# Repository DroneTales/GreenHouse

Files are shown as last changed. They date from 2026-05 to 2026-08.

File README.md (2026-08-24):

# Контроллер теплицы для Apple Home

Здесь вы найдете прошивку и схему контроллера теплицы, совместимого с Apple Home. Так же, здесь представлены Python скрипты для запуска логгера температуры и WEB-интерфейса контрля температуры, которые вы можете запустить на своем домашнем сервере. По любым вопросам добро пожаловать в мой [телеграм канале](t.me/drone_tales).  

**Используемые компоненты**

- LilyGO T-A7608E-H or T-A7608SA-H board - 1 шт.
- Датчик температуры DS18B20 - 1-10 шт.
- Транзистор 2N3906 - 1 шт.
- Транзистор 2N3904 - 1 шт.
- Резистор 100 Ohm - 1 шт.
- Резистор 1K - 2 шт.
- Резистор 4.7K - 1 шт.
- Резистор 47K - 1 шт.
- Конденсатор 3000mF x 6.3V - 1 шт.

**Используемые библиотеки Arduino**

- esp32 by Espressif Systems (board) 3.3.8
- esp32-ds18b20 2.0.3
- TinyGsmClient 0.12.0
- PubSubClient 2.8
 
**Настройки Arduino IDE**

- Board: ESP32 WROVER Kit (all versions)
- CPU Frequency: 80MHz (WiFi/BT)
- Core Debug Level: None
- Erase All Flash Before Sketch Upload: Disabled
- Flash frequency: 80Mhz
- Flash Mode: QIO
- Flash Size: 4MB (32Mb)
- Partition Scheme: Huge APP (3MB No OTA/1MB SPIFFS)
- PSRAM: Enabled
- Upload Speed: 921600

## 1. Подготовка домашней сети

Я предположу, что вы уже имеете настроенный и работающий у вас в сети **HomeBridge**. Вам также понадобится MQTT брокер, запущенный на вашем домашнем сервере. Следуйте [этим](https://github.com/DroneTales/VideoDoorbell) инструкциям для установки и настройки Mosquitto MQTT брокера. Я так же предполагаю, что вы знакомы с настройками вашего домашнего модема или роутера и способны произвести его конфигурацию.  

### 1.1. Проверка вашего IP адреса

В первую очередь мы должны узнать тип вашего внешнего IP адреса. Бывает три типа внешних IP адресов: статический белый, динамический белый и серый IP адрес. Термин **белый** означает, что IP адрес, назначенный вашему модему или роутеру, это тот же самый IP адрес, который виден из Internet. Термин **серый** означает, что IP адрес, назначенный вашему модему или роутеру, отличается от того, который виден из Internet (потому, что ваше устройство находится за NAT провайдеры). Я уверен, что если у вас белый внешний IP адрес, то вы точно об этом знаете, потому, что для получение такого адреса необходим договор с провайдером и ежемесячная оплата этой услуги. В этом случае вы можете смело пропустить части о серых адресах.  

Теперь нам нужно проверить тип вашего внешнего IP адреса. Для этого зайдите в WEB интерфейс вашего модема или роутера (далее я буду называть это устройство роутером) и посмотрите, какой адрес был назначен ему вашим Internet провайдером. Обычно, эта информация может быть найдена на странице "Статус". Если вы подключились к вашему роутеру по SSH, то выполните следующие команды, что бы посмотреть назначенный IP адрес.  

`cat /tmp/dhcp.leases`  
`ip addr show or ifconfig`  
`ip neigh`  
`arp -an`  

Точные команды зависят от прошивки вашего роутера. Но если вы работает с ним по SSH я могу смело предположить, что вы знаете как посмотреть IP адрес. Как только вы нашли назначенный IP адрес, откройте [эту](https://www.myip.com) страницу, что бы узнать, какой IP адрес видится извне.  

Если адреса совпадают (на странице вы видите тот же IP, что и на вашем роутере), то значит, что у вас белый внешний IP адрес, что очень хорошо. Если же IP адреса не совпадают, то у вас серый IP адрес и потребуются чуть больше работы для настройки внешнего подключения.  

Теперь, если у вас белый внешний IP и вы не уверены, статический он или динамический, то выполните следующие шаги, что бы узнать точный тип вашего внешнего IP адреса:  

- Запомните (или запишите) текущий IP адрес.
- **Выключите** ваш роутер.
- Подождите несколько минут.
- **Включите** ваш роутер.
- Проверьте назначенный IP адрес.

Возможно, потребуется выключить и включить можем несколько раз, для того, что бы провайдер сменил назначенный IP адрес. Если IP адрес не меняется, то у вас статический внешний IP адрес. Если меняется - то динамический.  

#### 1.1.1. Статический белый IP

Если у вас статический белый внешний IP, то никаких специальных действий делать не нужно.  

#### 1.1.2. Динамический белый IP

В случае, если у вас динамический белый внешний IP, вам понадобится настроить службу DynDNS на вашем роутере. Следуйте инструкции к вашему роутеру и выбранного DynDNS сервера для настройки.  

#### 1.1.3. Серый IP

Это худший вариант. Вам будет необходимо настроить **тунель** для того, что бы иметь возможность подключиться к вашей домашней сети из Internet. Так как мы будем в дальнейшем использовать **Cloudflare** в качестве DNS сервера, я рекомендую использоват **Cloudflare тунель**. Инструкции по настройки туннеля могут быть найдены [здесь](https://developers.cloudflare.com/tunnel/). Одно, прежде чем переходить к настройкам тунеля, прочитайте следующие части про доменное имя.  

### 1.2. Получение доменного имени

Если вы уже владеете каким-либо доменным именем, то вы можете пропустить эту часть. Однако, я рекомендую перенести ваш домен на Cloudflare потому, что мы будем использовать CloudFlare как DNS прокси для защиты вашей домашней сети от внешнего мира.  

Если вы не владеете доменным именем (для простоты - доменом) и у вас внешний белый статический или серый внешний IP адрес, то вам необходимо приобрести домен. Сервисов, которые предоставляют услуги регистрации доменных имен полно, но лично я использую два: Namecheap и Cloudflare. Для данного проекта будет лучше, если вы зарегистрируете доменное имя через Cloudflare, тогда вам не придется переносить его на Cloudflare позже.  

Если же у вас динамический белый внешний IP адрес, то доменное имя будет предоставлено сервисом DynDNS. Однако лучше обратиться к правилам оказания услуг вашего DynDNS сервиса для уточнения деталей.  

Далее я буду предполагать, что вы приобрели или перенесли ваш домен на Cloudflare. Если вы используете DynDNS, то можете пропустить все, что касается Cloudflare далее.  

### 1.3. Настройка записей DNS

К сожалению, если у вас динамический внешний IP и вы используете сервис DynDNS, то в большинстве случаев вы не сможете создать субдомены: имя вяшего домена будет выглядить как mygreenhouse.dyndns.com или что-то аналогичное. В других случаях (статический белый или серый IP), вы сможете создать субдомены и мы сделаем это для разделения графика и защиты домашней сети.  

Сайчса мы содадим два субдомена: **chart** и **broker**. Первый будет использоваться для доступа к WEB интерфейсу графика температур, а второй - для доступа к MQTT брокеру. Откройте панель управления доменом на Cloudflare (или другом регистраторе доменов, который вы используете). Добавьте две **A** записи. Допустим, что имя вашего домена **greenhouse.home** и ваш внешний IP **20.22.24.26**. Тогда первая **A** запись будет выглядеть как:  

`A  chart.greenhouse.home  20.22.24.26`  

Некоторые DNS сервера (точнее, их панели управления) используют обратную запись (что, в действительности, верно):  

`A  home.greenhouse.chart  20.22.24.26`  

В любом случе, добавьте вторую **A** запись для поддомена **broker**:  

`A  broker.greenhouse.home 20.22.24.26`  

или  

`A  home.greenhouse.broker  20.22.24.26`  

Если вы используете Cloudflare со статическим IP адресом, то сконфигурируйте первый субдомен (chart) как **Proxied**. Если у вас серый внешний IP, то следуйте инструкции по настройке тунеля Cloudflare. **Не забудьте открыть порты HTTP (80), HTTPS (443), и MQTT ports в настройках тунеля.** Вы можете использовать стандартный порт MQTT (1883), но будет лучше, если вы используете другой порт, например 23543.  

### 1.4. Настройка пробросал портов

Если вы используете CloudFlare тунель, то пропустите эту часть. В противном случае вам необходимо настроить проброс портов (Port Forwarding) на вашем роутере для того, что бы контроллер теплицы мог отправлять данные вашему MQTT брокеру и что бы вы имели доступ к WEB интерфейсу. Для этого зайдите в настройки вашего роутера и найдите раздел, который называется "Port Forwarding" или "Port Mapping". Добавьте следующие три правила, как показано в таблице ниже:  

| Comment |  Local IP | Start port | End port | Protocol | Remote IP | Start  port | End port  |  
|:---:|:---:|:---:|:---:|:---:|:---:|:---:|:---:|
|  MQTT | <homebridge> | 1883 | 1883 | TCP | | <mqtt_port> | <mqtt_port> |  
|  HTTP | <homebridge> | 80 | 80 | TCP | | 80 | 80 |  
|  HTTPS  | <homebridge> | 443 | 443 | TCP | | 443 | 443 |  

Где *<homebridge>* - IP адрес вашего HomeBridge сервера (скажем, *192.168.0.112*), а *<mqtt_port>* - порт MQTT брокера, который вы решили "выставить" наружу. Это может быть как стандартный MQTT порт - 1883, так и любой другой, который вам нравится. Например: *23543*.  

**Повторю: настраивать проброс портов нужно только в том случае, если у вас белый статический либо белый динамический внешний IP адрес. Если у вас серый внешний IP адрес, то все настройки должны быть произведены в клиенте и сервере Cloudflare туннеля. Обратитесь к инструкции по настройке туннеля Cloudflare за подробностями.**  

### 1.5. Проверка

Пришло время проверить ваши настройки и возможность доступа к вашему серверу из вне. Эта проверка не гарантирует, что ваш *HomeBridge* сервер доступен, она лишь проверяет ваш *роуетр*. Это позволит убедиться, что DNS настроены корректно. И так, откройте терминал (или командную строку на Windows) и выполните следующую команду:  

`ping <your_domain_name>`  

где *<your_domain_name>* - имя вашего субдомена, например:  

`ping chart.greenhouse.home`  
`ping broker.greenhouse.home`  

Вы должны увидеть что-то вроде этого:  

```
64 bytes from 20.22.24.26: icmp_seq=0 ttl=64 time=3.963 ms
64 bytes from 20.22.24.26: icmp_seq=1 ttl=64 time=4.059 ms
```

(Конечно, вместо 20.22.24.26, вы должны увидеть ваш IP адрес.). Если же вы видите что-то вроде:  

```
Request timeout for icmp_seq 0
Request timeout for icmp_seq 1
Request timeout for icmp_seq 2
```

значит что-то не так с настройками вашего DNS сервера или IP (может он **серый** или **за NAT**?).  

## 2. Определение адресов датчиков температуры

Теперь нам необходимо узнать адреса датчиков температуры, что бы мы могли их идетнифицировать в HomeBridge. Это не является необходимым, если у вас только один датчик, но если их несколько, то это очень важный шаг. Например у меня 4 датчика: 3 внутри теплицы и 1 снаружи. Два из тех, что внутри, расположены около дверей. И один - по центру теплицы. Для того, что бы знать, какой из них где, мне необходимо знать адрес каждого. Затем я помечу их цветными метками (например, термоусадкой). Прошивка поддерживает **вплоть дл 10** датчиков температуры.  

### 2.1. Сборка устройства

Прежде чем продожить мы должны собрать устройство. Используйте схему и вид платы из папки *wiring*. После сборки подлючите GSM антенну и не отключайте ее. Включение устройства без подключенной GSM антенны может вывести GSM модем из строя.  

При желании вы можете использовать любую плату на основе ESP32 для того, что бы определить адреса датчиков температуры, но я предположу, что вы будете использовать плату контроллера.  

### 2.2. Использование скетча FindSensors

Теперь откройте скетч **FindSensors** в Arduino IDE и прошейте вашу плату. После этого подключите первый сенсор и подключите плату. Откройте Serial Monitor в Arduino IDE. Если все собрано верно, то вы увидите адрес подключенного сенсора. Запишите этот адрес и пометьте сенсор каким-либо способом.  

Как это делал я: когда адрес сенсора найдет, я записывал его и помечал сенсор цветной термоусадкой. В итоге я получил таблицу вроде такой:  

9666714504207294760 - Черный  
18437195502557880616 - Белый  
290801794589212200 - Красный  
16791709353807948072 - Зеленый  

## 3. Настройка HomeBridge

Мы выполнили все необходимые приготовления и все выглядит работающим как надо. Так же у нас теперь есть список датчиков температуры. Теперь нам надо подготовить HomeBridge для получения данных с контроллера теплицы. Для этого откройте WEB интерфейс вашего HomeBridge, переключитесь на страницу *Plugins*, найдите и установите плагин **Homebridge MQTTThing**. Не беспокойтесь, он полностью совместим с последними версиями HomeBridge.  

После установки плагина перейдите на страницу JSON Config. Найдите раздел *"accessories"* в файле конфигурации. Если такой секйии там нет, то добавьте ее в самый конец конфигурационного файла (не забудьте добавить запятую после предыдущей секции):  

```
"accessories": [
]
```  

Если такая секция уже есть, то добавьте следующую конигурацию сразу за последним аксессуаром в этой секции (не забудьте про запятую!). Если вы только что создали этот раздел, то добавьте конфигурации между фигурными скобками (Я предполагаю, что у вас 4 датчика. Измените конфигурацию под ваши нужды при необходимости).  

```
{
    "accessory": "mqttthing",
    "type": "temperatureSensor",
    "name": "Outside",
    "manufacturer": "DroneTales",
    "model": "DS18B20",
    "firmwareRevision": "2.0",
    "serialNumber": "0_Black_966671",
    "minTemperature": -50,
    "maxTemperature": 60,
    "username": "mqtt_user_name",
    "password": "mqtt_password",
    "integerValue": true,
    "logMqtt": true,
    "topics": {
        "getBatteryLevel": "greenhouse/battery",
        "getStatusLowBattery": {
            "topic": "greenhouse/battery",
            "apply": "return message <= 20 ? true : false;"
        },
        "getCurrentTemperature": {
            "topic": "greenhouse/sensors/0",
            "apply": "if (!isNaN(message)) return message;"
        },
        "getStatusActive": {
            "topic": "greenhouse/sensors/0",
            "apply": "return isNaN(message) ? 0 : 1;"
        }
    }
},
{
    "accessory": "mqttthing",
    "type": "temperatureSensor",
    "name": "Zone 1",
    "manufacturer": "DroneTales",
    "model": "DS18B20",
    "firmwareRevision": "2.0",
    "serialNumber": "1_White_184371",
    "minTemperature": -50,
    "maxTemperature": 60,
    "username": "mqtt_user_name",
    "password": "mqtt_password",
    "integerValue": true,
    "logMqtt": true,
    "topics": {
        "getBatteryLevel": "greenhouse/battery",
        "getStatusLowBattery": {
            "topic": "greenhouse/battery",
            "apply": "return message <= 20 ? true : false;"
        },
        "getCurrentTemperature": {
            "topic": "greenhouse/sensors/1",
            "apply": "if (!isNaN(message)) return message;"
        },
        "getStatusActive": {
            "topic": "greenhouse/sensors/1",
            "apply": "return isNaN(message) ? 0 : 1;"
        }
    }
},
{
    "accessory": "mqttthing",
    "type": "temperatureSensor",
    "name": "Zone 2",
    "manufacturer": "DroneTales",
    "model": "DS18B20",
    "firmwareRevision": "2.0",
    "serialNumber": "2_Red_290801",
    "minTemperature": -50,
    "maxTemperature": 60,
    "username": "mqtt_user_name",
    "password": "mqtt_password",
    "integerValue": true,
    "logMqtt": true,
    "topics": {
        "getBatteryLevel": "greenhouse/battery",
        "getStatusLowBattery": {
            "topic": "greenhouse/battery",
            "apply": "return message <= 20 ? true : false;"
        },
        "getCurrentTemperature": {
            "topic": "greenhouse/sensors/2",
            "apply": "if (!isNaN(message)) return message;"
        },
        "getStatusActive": {
            "topic": "greenhouse/sensors/2",
            "apply": "return isNaN(message) ? 0 : 1;"
        }
    }
},
{
    "accessory": "mqttthing",
    "type": "temperatureSensor",
    "name": "Zone 3",
    "manufacturer": "DroneTales",
    "model": "DS18B20",
    "firmwareRevision": "2.0",
    "serialNumber": "3_Green_167917",
    "minTemperature": -50,
    "maxTemperature": 60,
    "username": "dronetales",
    "password": "dronetales",
    "integerValue": true,
    "logMqtt": true,
    "topics": {
        "getBatteryLevel": "greenhouse/battery",
        "getStatusLowBattery": {
            "topic": "greenhouse/battery",
            "apply": "return message <= 20 ? true : false;"
        },
        "getCurrentTemperature": {
            "topic": "greenhouse/sensors/3",
            "apply": "if (!isNaN(message)) return message;"
        },
        "getStatusActive": {
            "topic": "greenhouse/sensors/3",
            "apply": "return isNaN(message) ? 0 : 1;"
        }
    }
}
```

Я привел такую длинную конфигурация для того, что бы вы могли понять, как это устроено. Замените *mqtt_user_name* на имя пользователя вашего MQTT брокера, а *mqtt_password* - на пароль. Параметр *"name"* - имя сенсора по-умолчанию, которое появится в приложении Home после добавления сенсоров. Вы можете использовать любое, но я предпочитаю использовать нейтральные имена и потом переименовать сенсоры в приложении Home. Обратите внимание на параметр *"serialNumber"*. Я формировал его по следующему алгоритму *ID_сенсора_цвет_первые_6_цифр_адреса_сенсора*. Это позволяет определить сенсор в приложении Home и дать ему осмысленное имя в зависимости от расположения сенсора. Параметр *"topic"* должен оканчиваться порядковым номером сенсораp (0, 1, 2, 3, etc.). Надеюсь, это понятно.  

Сохраните конфигурацию и перезапустите HomeBridge. Если все сделано правильно, то после перезапуска HomeBridge вы увидите датчики температуры в приложении Home. Вам не нужно добавлять их вручную, они появятся автоматически.  

## 4. Прошивка контроллера теплицы

Откройте скетч *GreenHouse.ino* и прошейте плату. После этого подключите все сенсоры. **Не забудьте про GSM антенну!** Подключите аккумулятор 18650. Подключите внешнее питание (если требуется) к порту USB-C. **Не включайте плату!**  

### 4.1. Подготовка SD-Card

Теперь вам понадобится микро SD карта. Карта используется для хранения настроек GSM, MQTT, и датчиков температуры. Отформатируйте карту в **FAT32** и скопируйте на нее файл *config.txt*. Файл должен быть расположен в корне файловой системы карты.  

### 4.2. Обновление конфигурационного файла

Теперь вы должны изменить конфигурационный файл под ваши параметры. Откройте его в любом текстовом редакторе (убедитесь, что выбранный текстовый редактор может сохранить файл как простой текст в ASCII кодировке). Вы виде содержимое файл как показано ниже:  

```
[Board]
ShortSleep=120000000
LongSleep=900000000

[GPRS]
APN=mts
UserName=mts
Password=mts
PIN=1234

[MQTT]
Server=mqtt.server.name
Port=1883
UserName=mqtt_user_name
Password=mqtt_password
ClientID=GreenHouse

[Sensors]
Count=4
Address_0=9666714504207294760
Address_1=18437195502557880616
Address_2=290801794589212200
Address_3=16791709353807948072
```  

#### 4.2.1. Раздел Board

В этом разделе всего два параметра: **ShortSleep** и **LongSleep**. Параметр **ShortSleep** указывает время сна в микросекудах, которое используется, если плата не смогла отправить данные на сервер. Если отправка данных была неудачна, что плата заснет на этот период времени. Значение по-умолчанию - 2 минуты. Параметр **LongSleep** - это время сна в микросекундах, которое используется когда данные были успешно переданы. Значение по-умолчанию - 15 минут.  

#### 4.2.2. Раздел GPRS

Раздел *GPRS* содержит настройки вашей мобильной сети. Вы должны указать ваши **APN**, **username**, **password** и SIM **PIN**. Вы можете оставить пустыми те параметры, которые не требуются вашим мобильным оператором.  

#### 4.2.3. Раздел MQTT

Здесь вы должны указать настройки вашего MQTT брокера (сервера). Параметр **Server** - доменное имя вашего MQTT сервера (в примере, приведенном выше,  используется *broker.greenhouse.home*). Параметр **Port** - номер порта MQTT брокера (в нашем примере это *5555*). Параметры **UserName** и **Password**  - это имя пользователя и пароль для доступа к MQTT брокеру. Параметр **ClientID** - уникальное имя клиента **unique** MQTT брокера. Вы можете оставить его как есть.  

#### 4.2.4. Раздел Sensors

В этом разделе вы должны указать адреса своих датчиков температуры. В параметре **Count** нужно указать количество используемых датчиков. Затем, в каждом параметре **Address_n** должен быть указан *адрес датчика*. **N** соответствует номеру сообщения MQTT (*greenhouse/sensors/0*, *greenhouse/sensors/1*, и так далее) в конфигурации платина MQTT Things.  

### 4.3. Проверка оборудования

Все готово для первой проверки. Подключите датчики к плате контроллера, вставьте SD карту с файлом конфигурации, вставьте SIM карту и включите плату.  

Если все было собрано правильно и конфигруационный файл корректен, то через несколько секунд красный светодиод рядом с модемом начнет мигать, указывая на попытку отправить данные. Псоле отключения светодиода подождите немного. Если он начнет мигать опять через примерно 2 минуты, то данные не были переданы на сервер. В этом случае проверьте настройки вашего сервера, роутера, MQTT брокера и всего, что связано с локальной сетью и Internet.  

Если светодиод начнет повторно мигать через примерно 15 минут, то данные были успешно переданы и вы должны увидеть текущую температуру в приложении Home.  

Если светодиод не начинает мигать после включения спустя долгое время, то проблема с файлом конфигурацци. Выключите плату, извлеките SD карту и проверьте файл конфигурации  

## 5. Логгер температуры

Проект содержит два приложения: сервис **Temperature Logger** и WEB приложения **Temperature Monitor**. Приложения написаны на Python и JavaScript. Необходим **Python 3.11** и WEB серсвер **nginx**. В этом разделе вы найдете детальные инструкции по установке всего необходимого. По [этой](https://greenhouse.dronetales.net) вы можете посмотреть, как это выглядит в реальности.  

Снимок экрана — 2026-05-30 в 21 35 41

### 5.1. Установка зависимостей

Для запуска этих приложений вам потребуется Python 3.11 и nginx. Если у вас установлено одно из этих приложений, просто пропустите соответствующий шаг.  

#### 5.1.1. Установка Python

Для начала давайте установим Python 3.11. Для этого зайдите на свой сервер HomeBridge через SSH и выполните следующую команду:  

```
sudo apt update
sudo apt install python3.11 python3.11-venv
```  

#### 5.1.2. Установка nginx

Теперь нам необходимо установить nginx и certbot. Последний нужен для того, что бы получить SSL сертификат с сервиса Let's Encrypt. Для установки nginx выполните следующую команду:  

`sudo apt install nginx certbot python3-certbot-nginx`  

### 5.2. Подготовка директорий

Все файлы приложений будут храниться в директории /opt/greenhouse/. Структура директорий должна выглядеть как показано ниже:  

```
/opt/greenhouse/  
├── static/  
│   ├── css/  
│   │   └── style.css         # Styles definitions for web pages  
│   │  
│   └── js/  
│       ├── app.js            # Dashboard frontend  
│       ├── date-adapter.js   # Date-time adapter  
│       └── sensors.js        # Sensors page frontend  
│  
├── templates/  
│   ├── index.html            # Dashboard page  
│   └── sensors.html          # Sensors configuration page  
│  
├── .venv/                    # Python virtual environment  
├── const.py                  # Constants used by both applications  
├── db.py                     # Database settings  
├── logger.py                 # Temperature logger application  
├── sensors.py                # Sensors configuration  
├── server.py                 # Flask web application  
└── settings.py               # Application settings  
```

Владельцем всех директорий должен выступать текущий пользователь. В моем случае это пользователь *homebridge*. В команде ниже замените *homebridge* на имя вашего пользователя.  

```
sudo mkdir /opt/greenhouse
sudo chown homebridge:homebridge /opt/greenhouse
cd /opt/greenhouse
mkdir static
mkdir static/css
mkdir static/js
mkdir templates
```  

#### 5.2.1. Настройка Python Virtual Environment

```
python3.11 -m venv .venv
source .venv/bin/activate
pip install Flask waitress
source deactivate
```

#### 5.2.2. Загрузка библиотеки Chart.js

```
cd /opt/greenhouse/static/js
wget -O chart.js https://cdn.jsdelivr.net/npm/chart.js@4.4.0/dist/chart.umd.min.js
```  

#### 5.2.3. Установка файлов приложения

Теперь скопируйте все файлы из директории **Logger** в директорию **/opt/greenhouse** на вашем **HomeBridge** сервере. Если вы столкнулись с любой проблемой в процессе копирования, вы можете использовать следующий трюк: используйте текстовый редактор nano на вашем сервере HomeBridge, откройте файл локально и скопируйте-вставьте содержимое соответствующего файла в nano. Не самый быстрый способ, но зато 100% рабочий.  

Не забудьте изменить файл **settings.py** обновив следующие строки:  

```
MQTT_SERVER     = "mqtt_server_ip"
MQTT_USER_NAME  = "mqtt_user_name"
MQTT_PASSWORD   = "mqtt_password"
```

Замените *mqtt_server_ip* на корректный IP адрес вашего MQTT брокера; *mqtt_user_name* - на корректное имя пользователя и *mqtt_password* - на корректный пароль.  

### 5.3. Установка и запуск системного сервиса

Теперь необходимо настроить приложения, что бы они выполнялись как системный сервис.  

#### 5.3.1. Запуск WEB приложения как системный сервис

Выполните следующую команду:  

`sudo nano /etc/systemd/system/greenhouse-web.service`  

Затем вставьте следующее содержимое в созданный файл:  

```
[Unit]
Description=Greenhouse Web Dashboard
After=network.target

[Service]
Type=simple
User=homebridge
Group=homebridge
WorkingDirectory=/opt/greenhouse
ExecStart=/opt/greenhouse/.venv/bin/python /opt/greenhouse/server.py
Restart=on-failure
RestartSec=5

[Install]
WantedBy=multi-user.target
```

Подключаем и запускаем сервис.  

```
sudo systemctl daemon-reload
sudo systemctl enable greenhouse-web
sudo systemctl start greenhouse-web
```  

#### 5.3.2. Запуск приложения Logger как системный сервис

Выполните следующую команду:  

`sudo nano /etc/systemd/system/greenhouse-logger.service`  

Затем вставьте следующее содержимое в созданный файл:  

```
[Unit]
Description=Greenhouse MQTT Logger
After=network.target

[Service]
Type=simple
User=homebridge
Group=homebridge
WorkingDirectory=/opt/greenhouse
ExecStart=/opt/greenhouse/.venv/bin/python /opt/greenhouse/logger.py
Restart=on-failure
RestartSec=10

[Install]
WantedBy=multi-user.target
```  

Подключение и запуск сервиса **Logger**.

```
sudo systemctl daemon-reload
sudo systemctl enable greenhouse-logger
sudo systemctl start greenhouse-logger
```

### 5.4. Настройка nginx

Выполните следующую команду:  

`sudo nano /etc/nginx/sites-available/greenhouse`

Вставьте следующее содержимое в созданный файл.  

```
server {
    listen 80;
    server_name chart.greenhouse.home;

    location / {
        proxy_pass http://127.0.0.1:5000;
        proxy_set_header Host $host;
        proxy_set_header X-Real-IP $remote_addr;
        proxy_set_header X-Forwarded-For $proxy_add_x_forwarded_for;
        proxy_set_header X-Forwarded-Proto $scheme;
    }
}
```

Замените *chart.greenhouse.home* на имя вашего домена.  

Подключите сайт.  

```
sudo ln -s /etc/nginx/sites-available/greenhouse /etc/nginx/sites-enabled/
sudo nginx -t
sudo systemctl reload nginx
```  

### 5.5. Получение SSL сертификата

`sudo certbot --nginx -d chart.greenhouse.home`  

замените *chart.greenhouse.home* на имя вашего домена.  

Следуйте инструкции. Certbot автоматически изменит конфигурацию Nginx для работы с SSL и протоколом HTTPS.  

#### 5.5.1. Настройка автообновления SSL сертификата

Certbot сам настроит таймер systemd. Проверьте, что он активен:  

`sudo systemctl status certbot.timer`  

Проверить процесс автообновление можно следующей командой:  

`sudo certbot renew --dry-run`  

Перезапустите nginx:  

`sudo nginx -t && sudo systemctl reload nginx`

**Надеюсь, я не забыл ничего важного.**  

Если у вас возникли какие-либо вопросы, вы можете задать их в моем [телеграм канале](t.me/drone_tales).

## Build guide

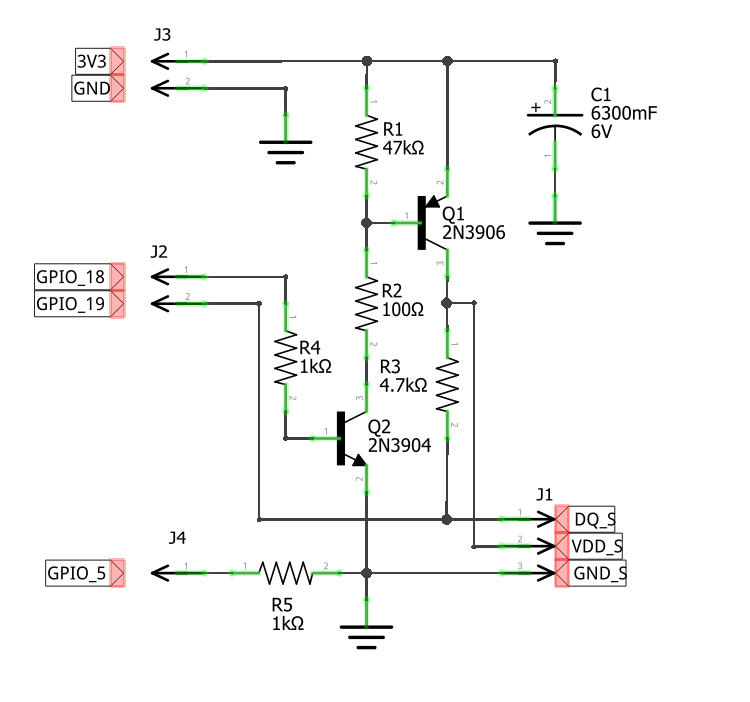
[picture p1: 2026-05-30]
wiring/wiring.png

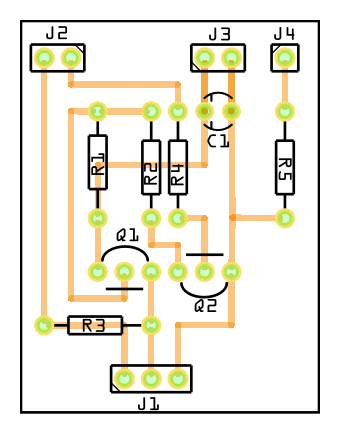
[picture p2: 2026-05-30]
wiring/pcb.png

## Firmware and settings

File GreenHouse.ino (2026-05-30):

// LilyGO T-A7608E-H board
// =============================================================================
// Arduino IDE settings:
//   - Board: ESP32 WROVER Kit (all versions)
//   - CPU Frequency: 80MHz (WiFi/BT)
//   - Core Debug Level: None
//   - Erase All Flash Before Sketch Upload: Disabled
//   - Flash frequency: 80Mhz
//   - Flash Mode: QIO
//   - Flash Size: 4MB (32Mb)
//   - Partition Scheme: Huge APP (3MB No OTA/1MB SPIFFS)
//   - PSRAM: Enabled
//   - Upload Speed: 921600
// =============================================================================

#include "Batt.h"
#include "Config.h"
#include "Modem.h"
#include "Mqtt.h"
#include "Sensors.h"

#include <esp_bt.h>
#include <esp_bt_main.h>
#include <esp_wifi.h>

#include <soc/rtc_cntl_reg.h>
#include <soc/soc.h>


/******************************************************************************/
/*                              Board  constants                              */

// The default sleep duration when configuration read failed. It allows user
// to insert SD card.
constexpr uint64_t DEFAULT_SLEEP_DURATION = (15 * 60 * 1000000);

/******************************************************************************/


/******************************************************************************/
/*                           Board helper functions                           */

// Disables Bluetooth and Wi-Fi units.
void DisableWirelessHardware()
{
    esp_bluedroid_disable();
    esp_bt_controller_disable();
    esp_wifi_stop();
}

// Hibernates the board.
void Hibernate(uint64_t SleepDuration)
{
    // Prepare board for going to deep sleep.
    esp_sleep_pd_config(ESP_PD_DOMAIN_RTC_PERIPH, ESP_PD_OPTION_ON);
    esp_sleep_pd_config(ESP_PD_DOMAIN_RTC_PERIPH, ESP_PD_OPTION_OFF);
    
    esp_sleep_pd_config(ESP_PD_DOMAIN_RTC_SLOW_MEM, ESP_PD_OPTION_ON);
    esp_sleep_pd_config(ESP_PD_DOMAIN_RTC_SLOW_MEM, ESP_PD_OPTION_OFF);
    
    esp_sleep_pd_config(ESP_PD_DOMAIN_RTC_FAST_MEM, ESP_PD_OPTION_ON);
    esp_sleep_pd_config(ESP_PD_DOMAIN_RTC_FAST_MEM, ESP_PD_OPTION_OFF);
    
    esp_sleep_pd_config(ESP_PD_DOMAIN_XTAL, ESP_PD_OPTION_ON);
    
    // Set the wakeup timer.
    esp_sleep_enable_timer_wakeup(SleepDuration);
    
    // Start deep sleep.
    esp_deep_sleep_start();
}

/******************************************************************************/


/******************************************************************************/
/*                           Data helper  functions                           */

// Collects data from battery and sensors.
void CollectData(SENSORS_CONFIG& SensorsConfig, BATTERY_INFO& BatteryInfo,
    SENSORS_DATA& SensorsData)
{
    // Get on-board battery data.
    BattGetInfo(BatteryInfo);
    // Then read temperature data.
    SensorsGetTemperature(SensorsConfig, SensorsData);
}

// Publishes data to the MQTT broker. Returns true if the data was published.
// Returns false otherwise.
bool PublishData(const CONFIG& Config, const BATTERY_INFO& BatteryInfo,
    const SENSORS_DATA& SensorsData)
{
    // First, turn on the on-board modem unit.
    if (!ModemTurnOn())
        return false;
    
    bool Result = false;
    
    // Try to connect to a mobile network.
    if (ModemConnectToNetwork(Config.Gprs.Pin))
    {
        // Once network connect, try to connect to GPRS.
        if (ModemConnectToGprs(Config.Gprs))
        {
            // Ok, once we have internet connection we can try to
            // connect to MQTT broker.
            if (MqttConnect(Config.Mqtt))
            {
                // Publish sensors data.
                Result = MqttPublish(BatteryInfo, SensorsData);
                // Disconnect from MQTT broker.
                MqttDisconnect();
            }
            // Disconnect from GPRS service.
            ModemDisconnectFromGprs();
        }
    }
    // Turns off the modem unit.
    ModemTurnOff();
    
    return Result;
}

/******************************************************************************/


/******************************************************************************/
/*                             Arduino  functions                             */

void setup()
{
    // The very first thing we have to do is to disable brownout detection.
    uint32_t BownOutState = READ_PERI_REG(RTC_CNTL_BROWN_OUT_REG);
    WRITE_PERI_REG(RTC_CNTL_BROWN_OUT_REG, 0);

    // Initialize the on-board battery.
    BattInit();
    // Initialize the on-board modem unit.
    ModemInit();
    // Initialize the temperature sensors hardware.
    SensorsInit();

    // Disable all wireless features because we do not use them.
    DisableWirelessHardware();
    
    // Power up the on-board hardware by enabling the on-board battery.
    BattEnable();
    
    // Set default sleep duration. We use it if the SD-card is not inserted
    // or if the configuration file was not found or is not valid.
    // This sleep duration allows a user to insert the SD-card.
    uint64_t SleepDuration = DEFAULT_SLEEP_DURATION;
    // Now read configuration.
    CONFIG Config;
    if (ConfigRead(Config))
    {
        // OK, configuration read with success. We can set sleep interval to
        // short one assuming data publishing failed.
        SleepDuration = Config.Board.ShortSleep;

        // Collect information from sensors.
        BATTERY_INFO BatteryInfo;
        SENSORS_DATA SensorsData;
        CollectData(Config.Sensors, BatteryInfo, SensorsData);

        // All data callected. We can try to send it to the MQTT broker.
        if (PublishData(Config, BatteryInfo, SensorsData))
            // If data was published then we can set the sleep duration
            // to a long period.
            SleepDuration = Config.Board.LongSleep;
    }

    // Turn off the on-board harware by disable the on-board battery
    // power source.
    BattDisable();
    
    // We must restore the brown-out detection state before goint
    // to sleep.
    WRITE_PERI_REG(RTC_CNTL_BROWN_OUT_REG, BownOutState);
    
    // Hibernate the board for the specified period of time.
    Hibernate(SleepDuration);
}

void loop()
{
}

/******************************************************************************/

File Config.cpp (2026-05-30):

#include "Config.h"
#include "Pins.h"

#include <FS.h>
#include <SD.h>
#include <SPI.h>


/******************************************************************************/
/*                          Configuration  constants                          */

// The configuration INI file name.
const char* const INI_FILE_NAME = "/config.txt";

/*                          INI file section  names                          */

// The board configuration section name.
const char* const SECTION_BOARD = "Board";
// GPRS configuration section name.
const char* const SECTION_GPRS = "GPRS";
// MQTT section name.
const char* const SECTION_MQTT = "MQTT";
// Temperature sensors section name.
const char* const SECTION_SENSORS = "Sensors";

/*                      INI file board section key names                      */

// The long sleep (success or no config file) interval key name.
const char* const KEY_BOARD_LONG_SLEEP = "LongSleep";
// The short sleep (failed) interval key name.
const char* const KEY_BOARD_SHORT_SLEEP = "ShortSleep";

/*                      INI file GPRS section  key names                      */

// The APN key name.
const char* const KEY_GPRS_APN = "APN";
// The password key name.
const char* const KEY_GPRS_PASSWORD = "Password";
// The user name key name.
const char* const KEY_GPRS_USER_NAME = "UserName";
// The SIM PIN key name.
const char* const KEY_GPRS_SIM_PIN = "Pin";

/*                      INI file MQTT section  key names                      */

// MQTT client ID key name.
const char* const KEY_MQTT_CLIENT_ID = "ClientID";
// The password key name.
const char* const KEY_MQTT_PASSWORD = "Password";
// MQTT broker key name.
const char* const KEY_MQTT_SERVER_NAME = "Server";
// MQTT broker port key name,
const char* const KEY_MQTT_SERVER_PORT = "Port";
// The user name key name.
const char* const KEY_MQTT_USER_NAME = "UserName";

/*                     INI file sensors section key names                     */

// Number of sensors key name.
const char* const KEY_SENSORS_COUNT = "Count";
// Sensor address key name.
const char* const KEY_SENSORS_ADDRESS = "Address_%u";

/******************************************************************************/


/******************************************************************************/
/*                   Configuration SD-card helper functions                   */

// Mounts the SD-card. Returns true if the SD-card found. Returns
// false otherwise.
bool Mount()
{
	// Set SD card reader pins.
    pinMode(TF_CARD_CS_PIN, OUTPUT);
    digitalWrite(TF_CARD_CS_PIN, LOW);

    // Initialize SPI bus.
    if (!SPI.begin(TF_CARD_SCLK_PIN, TF_CARD_MISO_PIN, TF_CARD_MOSI_PIN, TF_CARD_CS_PIN))
        return false;

	// Mount SD card.
    if (!SD.begin(TF_CARD_CS_PIN, SPI))
    {
		// If card is not inserted then release the SPI bus.
		SPI.end();
		// And return error.
		return false;
	}
	
	// It looks like card is inserted.
	return true;
}

// Unmount the SD-card.
void Unmount()
{
	// Release the card reader.
	SD.end();
	// Release the SPI bus.
	SPI.end();
}

/******************************************************************************/


/******************************************************************************/
/*                  Configuration INI file helper  functions                  */

// Returns true if the specified buffer is empty string.
bool IsEmpty(const char* const Buffer)
{
    return (Buffer[0] == '\0');
}

// Returns true if the string in the specified buffer is a comment.
bool IsComment(const char* const Buffer)
{
    return (Buffer[0] == '#' || Buffer[0] == ';');
}

// Returns true if the string is a section name.
bool IsSection(const char* const Buffer)
{
    return (Buffer[0] == '[' || Buffer[0] == ']');
}

// Returns true if the string is a key-value pair.
bool IsKeyValuePair(const char* const Buffer)
{
    return (strlen(Buffer) > 1 && strchr(Buffer, '=') != NULL &&
            Buffer[0] != '=');
}

// Returns true if the string is a valid section name.
bool IsValidSection(const char* const Buffer)
{
    size_t Len = strlen(Buffer);
    return (Len > 2 && Buffer[0] == '[' && Buffer[Len - 1] == ']');
}

// Clears the string.
void Clear(char* const Buffer)
{
    Buffer[0] = '\0';
}

// Removes tralling and ending spaces from the specified string.
void Trim(char* const Buffer)
{
    if (IsEmpty(Buffer))
        return;
    
    size_t Pos = 0;
    size_t Len = strlen(Buffer);
    while (isspace(Buffer[Pos]) && Pos < Len)
        Pos++;
    if (Pos == Len)
    {
        Clear(Buffer);
        return;
    }
    strcpy(Buffer, &Buffer[Pos]);
    
    Pos = strlen(Buffer) - 1;
    while (isspace(Buffer[Pos]) && Pos > 0)
        Pos--;
    Buffer[Pos + 1] = '\0';
}
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

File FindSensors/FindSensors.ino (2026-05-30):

#include "OneWireESP32.h"


// Comment this line if you do not use separate power pin for power up
// DS18B20.
#define _USE_POWER_PIN_

// Power enable pin.
#define SENSOR_POWER_PIN	GPIO_NUM_18
// Sensor DQ pin.
#define SENSOR_DATA_PIN		GPIO_NUM_19


const uint8_t MaxDevs = 10;
float currTemp[MaxDevs];


void setup()
{
	#ifdef _USE_POWER_PIN_
		// Power on sensors.
		pinMode(SENSOR_POWER_PIN, OUTPUT);
		digitalWrite(SENSOR_POWER_PIN, HIGH);
	#endif

	OneWire32 ds(SENSOR_DATA_PIN);
	
	delay(1000);
	Serial.begin(115200);
	
	uint64_t addr[MaxDevs];
	uint8_t devices = ds.search(addr, MaxDevs);
	for (uint8_t i = 0; i < devices; i += 1)
		Serial.printf("%d: 0x%llx [%llu]\n", i, addr[i], addr[i]);

	ds.request();
	delay(750);
	for (uint8_t i = 0; i < MaxDevs; i++)
	{
		uint8_t err = ds.getTemp(addr[i], currTemp[i]);
		if (err)
		{
			const char *errt[] = {"", "CRC", "BAD","DC","DRV"};
			Serial.print(i); Serial.print(": "); Serial.println(errt[err]);
		}
		else
			Serial.print(i); Serial.print(": "); Serial.println(currTemp[i]);
	}
}


void loop()
{
}

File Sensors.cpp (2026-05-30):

#include "Pins.h"
#include "Sensors.h"

#include <OneWireESP32.h>


/******************************************************************************/
/*                       Temperature sensors  constants                       */

// Delay after powering up sensors.
constexpr uint32_t SENSORS_INIT_DELAY = 1000;
// Delay before temperature reading.
constexpr uint32_t SENSORS_READING_DELAY = 750;

/******************************************************************************/


/******************************************************************************/
/*                       Temperature sensors  functions                       */

// Initializes the temperature sensors hardware.
void SensorsInit()
{
    // Initialize the temperature sensors pins. We must do it to remove
    // power from the sensors.
    pinMode(DS18B20_POWER_PIN, OUTPUT);    
    // Disable the sensors power.
    digitalWrite(DS18B20_POWER_PIN, LOW);
}

// Reads temperature values from the temperature sensors.
void SensorsGetTemperature(SENSORS_CONFIG& Config, SENSORS_DATA& Data)
{
    // Turns sensor on.
    digitalWrite(DS18B20_POWER_PIN, HIGH);
    // Wait for sensors initialization.
    delay(SENSORS_INIT_DELAY);
    
    // Initializa DS18B20 sensor.
    OneWire32 Sensor(DS18B20_PIN);
    
    // Request temperature from all connected sensros.
    Sensor.request();
    delay(SENSORS_READING_DELAY);
    
    // Read temperature.
    Data.Count = Config.Count;
    for (uint8_t i = 0; i < Config.Count; i++)
    {
        // getTemp return 0 if success!
        if (Sensor.getTemp(Config.Address[i], Data.Sensors[i]))
            Data.Sensors[i] = NAN;
    }
    
    // Turns sensor off.
    digitalWrite(DS18B20_POWER_PIN, LOW);
}

/******************************************************************************/
